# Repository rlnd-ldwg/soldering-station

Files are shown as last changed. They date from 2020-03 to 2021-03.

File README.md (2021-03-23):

# soldering-station
### based on Weller soldering tip

improved fork from ArduinoHannover/Maiskolben  

features:  
* optional referenzvoltage for A/D conversion based on LM4040
* optional PWM controlled TFT brightness
* using ATmega328p as mcu
* rotary encoder to set temperature
* prototyping area for own development
* voltage converter for I2C interface

for more information see the original README under README-MAISKOLBEN.md (german)

Beim Drehenkoder müssen A und S1 getauscht werden!

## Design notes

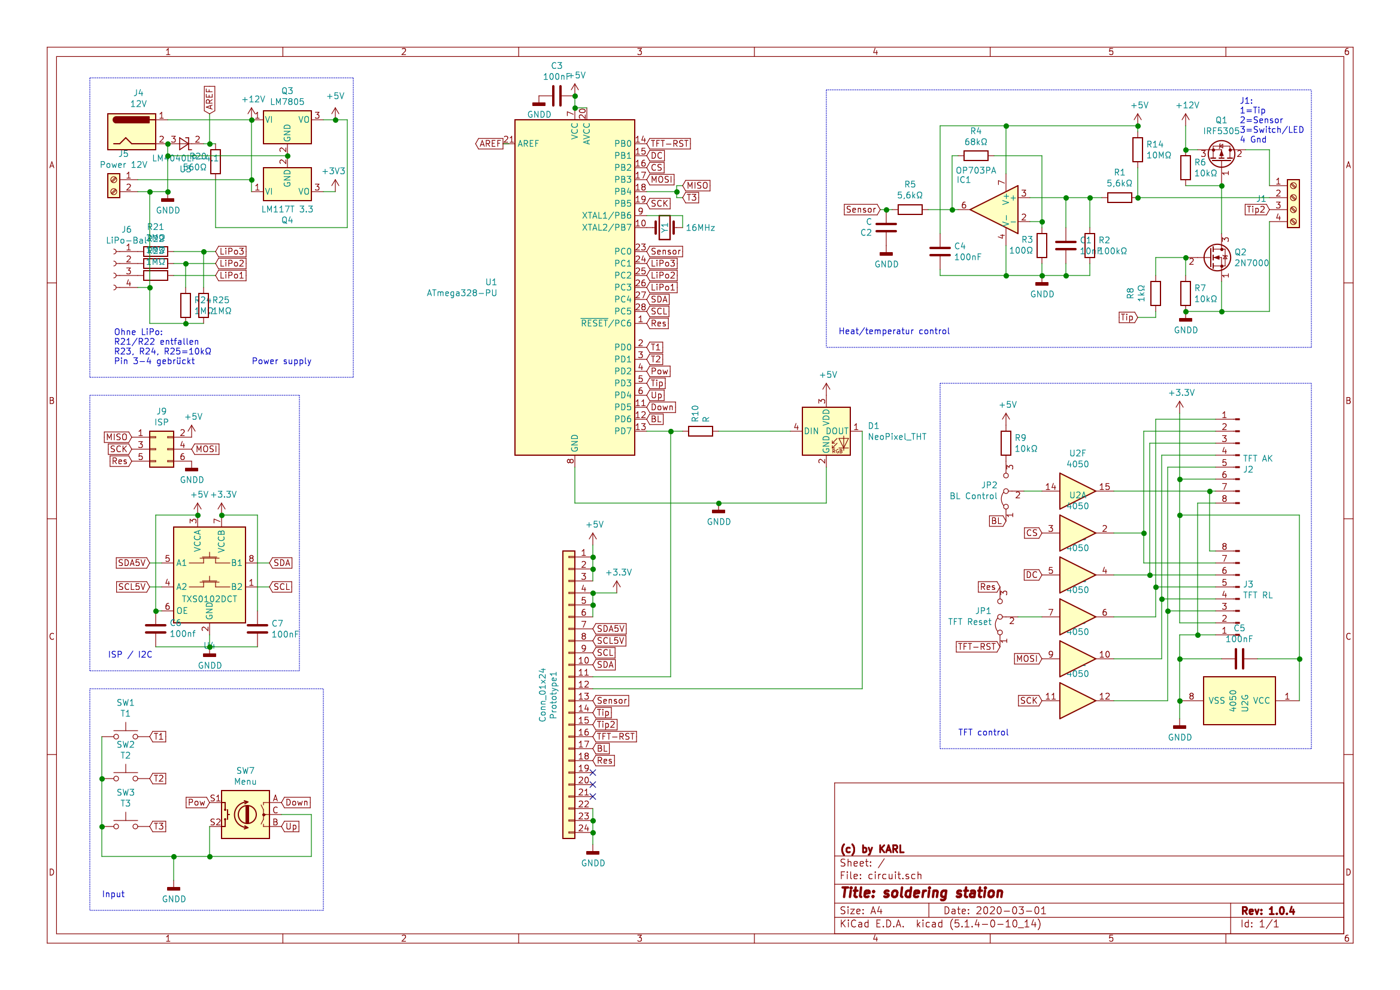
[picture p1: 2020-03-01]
images/circuit.png

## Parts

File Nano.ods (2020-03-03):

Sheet: Pinout ATmega
ATmega328 | 28 PDIP | 32 TQFP | Maiskolben | neu | Arduino | Function
PC6 | 1 | 29 | Reset | Reset |  |  | PCINT14 | RESET
PD0 | 2 | 30 | - | T1 | D0 |  | PCINST16 | RXD
PD1 | 3 | 31 | - | T2 | D1 |  | PCINT17 | TXD
PD2 | 4 | 32 | Power | Power | D2 |  | PCINT18 | INT0
PD3 | 5 | 1 | Heat PWM | Heat PWM | D3 | OC2B | PCINT19 | INT1
PD4 | 6 | 2 | Down | T+(Up) | D4 | T0 | PCINT20 | XCK
PB6 | 9 |  | Xtal | Xtal
PB7 | 10 |  | Xtal | Xtal
PD5 | 11 | 9 | LED | T-(Down) | D5 | T1 | PCINT21 | OC0B
PD6 | 12 | 10 | Up | BL | D6 | AIN0 | PCINT22 | OC0A
PD7 | 13 | 11 | T3 | LED | D7 | AIN1 | PCINT23
PB0 | 14 | 12 | T2 | TFT Reset | D8 | CLK0 | PCINT0 | ICP1
PB1 | 15 | 13 | T1 | DC | D9 | OC1A | PCINT1
PB2 | 16 | 14 | CS | CS | D10 | OC1B | PCINT2 | SS
PB3 | 17 | 15 | MOSI | MOSI | D11 | OC2A | PCINT3 | MOSI
PB4 | 18 | 16 | - | T3 | D12 |  | PCINT4 | MISO
PB5 | 19 | 17 | SCK | SCK | D13 |  | PCINT5 | SCK
AREF | 21 | 21 | - | Vref
PC0 | 23 | 23 | Temp | Tempsensor | A0 | ADC0 | PCINT8
PC1 | 24 | 24 | Stdb | Bat3 | A1 | ADC1 | PCINT9
PC2 | 25 | 25 | Bat3 | Bat2 | A2 | ADC2 | PCINT10
PC3 | 26 | 26 | Bat2 | Bat1 | A3 | ADC3 | PCINT11
PC4 | 27 | 27 | Bat1 | SDA | A4 | ADC4 | PCINT12 | SDA
PC5 | 28 | 28 | DC | SCL | A5 | ADC5 | PCINT13 | SCL
ADC6 |  | 19 |  |  | A6 | ADC6
ADC7 |  | 22 |  |  | A7 | ADC7

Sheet: BOM
Source: | /Users/roland/Projects/soldering-station/KiCad/circuit.sch
Date: | 2020 March 01, Sunday 12:34:07 | Tool: Eeschema (5.1.4-0-10_14)
Component Count: | 49
Ref | Value | Footprint | Datasheet | Manufacturer | Vendor
C1 | 10nF | Capacitor_THT:C_Disc_D4.3mm_W1.9mm_P5.00mm | ~
C2 | C | Capacitor_THT:C_Disc_D4.3mm_W1.9mm_P5.00mm | ~
C3 | 100nF | Capacitor_THT:C_Disc_D4.3mm_W1.9mm_P5.00mm | ~
C4 | 100nF | Capacitor_THT:C_Disc_D4.3mm_W1.9mm_P5.00mm | ~
C5 | 100nF | Capacitor_THT:C_Disc_D4.3mm_W1.9mm_P5.00mm | ~
C6 | 100nf | Capacitor_THT:C_Disc_D4.3mm_W1.9mm_P5.00mm | ~
C7 | 100nF | Capacitor_THT:C_Disc_D4.3mm_W1.9mm_P5.00mm | ~
D1 | NeoPixel_THT | LED_THT:LED_D5.0mm-4_RGB | https://www.adafruit.com/product/1938
IC1 | OP703PA | Package_DIP:DIP-8_W7.62mm | https://www.analog.com/media/en/technical-documentation/data-sheets/OP179_279.pdf
J1 | Soldering iron | TerminalBlock_Phoenix:TerminalBlock_Phoenix_MKDS-1,5-4-5.08_1x04_P5.08mm_Horizontal | ~
J2 | TFT AK | my:TFT-1.8-AK | ~
J3 | TFT RL | my:TFT-1.8-RGB | ~
J4 | 12V | Connector_BarrelJack:BarrelJack_CUI_PJ-063AH_Horizontal | ~
J5 | Power 12V | TerminalBlock_Phoenix:TerminalBlock_Phoenix_MKDS-1,5-2-5.08_1x02_P5.08mm_Horizontal | ~
J6 | LiPo-Bal | Connector_JST:JST_EH_S4B-EH_1x04_P2.50mm_Horizontal | ~
J9 | ISP | Connector_PinHeader_2.54mm:PinHeader_2x03_P2.54mm_Vertical | ~
JP1 | TFT Reset | Connector_PinHeader_2.54mm:PinHeader_1x03_P2.54mm_Vertical | ~
JP2 | BL Control | Connector_PinHeader_2.54mm:PinHeader_1x03_P2.54mm_Vertical | ~
Prototype1 | Conn_01x24 | my:Proto1x24 | ~
Q1 | IRF5305 | Package_TO_SOT_THT:TO-220-3_Horizontal_TabDown | http://www.infineon.com/dgdl/irf4905.pdf?fileId=5546d462533600a4015355e32165197c
Q2 | 2N7000 | Package_TO_SOT_THT:TO-92_Inline | https://www.fairchildsemi.com/datasheets/2N/2N7000.pdf
Q3 | LM7805 | Package_TO_SOT_THT:TO-220-3_Horizontal_TabDown | http://www.fairchildsemi.com/ds/LM/LM7805.pdf
Q4 | LM117T 3.3 | Package_TO_SOT_THT:TO-220-3_Horizontal_TabDown | http://www.fairchildsemi.com/ds/LM/LM7805.pdf
R1 | 5,6kΩ | Resistor_THT:R_Axial_DIN0204_L3.6mm_D1.6mm_P7.62mm_Horizontal | ~
R2 | 100kΩ | Resistor_THT:R_Axial_DIN0204_L3.6mm_D1.6mm_P7.62mm_Horizontal | ~
R3 | 100Ω | Resistor_THT:R_Axial_DIN0204_L3.6mm_D1.6mm_P7.62mm_Horizontal | ~
R4 | 68kΩ | Resistor_THT:R_Axial_DIN0204_L3.6mm_D1.6mm_P7.62mm_Horizontal | ~
R5 | 5,6kΩ | Resistor_THT:R_Axial_DIN0204_L3.6mm_D1.6mm_P7.62mm_Horizontal | ~
R6 | 10kΩ | Resistor_THT:R_Axial_DIN0204_L3.6mm_D1.6mm_P7.62mm_Horizontal | ~
R7 | 10kΩ | Resistor_THT:R_Axial_DIN0204_L3.6mm_D1.6mm_P7.62mm_Horizontal | ~
R8 | 1kΩ | Resistor_THT:R_Axial_DIN0204_L3.6mm_D1.6mm_P7.62mm_Horizontal | ~
R9 | 10kΩ | Resistor_THT:R_Axial_DIN0204_L3.6mm_D1.6mm_P7.62mm_Horizontal | ~
R10 | 220Ω/0Ω | Resistor_THT:R_Axial_DIN0204_L3.6mm_D1.6mm_P7.62mm_Horizontal | ~
R14 | 10MΩ | Resistor_THT:R_Axial_DIN0204_L3.6mm_D1.6mm_P7.62mm_Horizontal | ~
R20 | 560Ω | Resistor_THT:R_Axial_DIN0204_L3.6mm_D1.6mm_P7.62mm_Horizontal | ~
R21 | 2MΩ | Resistor_THT:R_Axial_DIN0204_L3.6mm_D1.6mm_P7.62mm_Horizontal | ~
R22 | 1MΩ | Resistor_THT:R_Axial_DIN0204_L3.6mm_D1.6mm_P7.62mm_Horizontal | ~
R23 | 1MΩ | Resistor_THT:R_Axial_DIN0204_L3.6mm_D1.6mm_P7.62mm_Horizontal | ~
R24 | 1MΩ | Resistor_THT:R_Axial_DIN0204_L3.6mm_D1.6mm_P7.62mm_Horizontal | ~
R25 | 1MΩ | Resistor_THT:R_Axial_DIN0204_L3.6mm_D1.6mm_P7.62mm_Horizontal | ~
SW1 | T1 | Button_Switch_THT:SW_Tactile_Straight_KSL0Axx1LFTR | ~
SW2 | T2 | Button_Switch_THT:SW_Tactile_Straight_KSL0Axx1LFTR | ~
SW3 | T3 | Button_Switch_THT:SW_Tactile_Straight_KSL0Axx1LFTR | ~
SW7 | Menu | Rotary_Encoder:RotaryEncoder_Alps_EC11E-Switch_Vertical_H20mm | ~
U1 | ATmega328-PU | Package_DIP:DIP-28_W7.62mm | http://ww1.microchip.com/downloads/en/DeviceDoc/ATmega328_P%20AVR%20MCU%20with%20picoPower%20Technology%20Data%20Sheet%2040001984A.pdf
U2 | 4050 | Package_DIP:DIP-16_W7.62mm | http://www.intersil.com/content/dam/intersil/documents/cd40/cd4050bms.pdf
U3 | LM4040LP-4.1 | Package_TO_SOT_THT:TO-92_Inline | http://www.ti.com/lit/ds/symlink/lm4040-n.pdf
U4 | TXS0102DCT | Package_DIP:DIP-8_W7.62mm | http://www.ti.com/lit/gpn/txs0102
Y1 | 16MHz | Crystal:Crystal_HC49-U_Vertical | ~

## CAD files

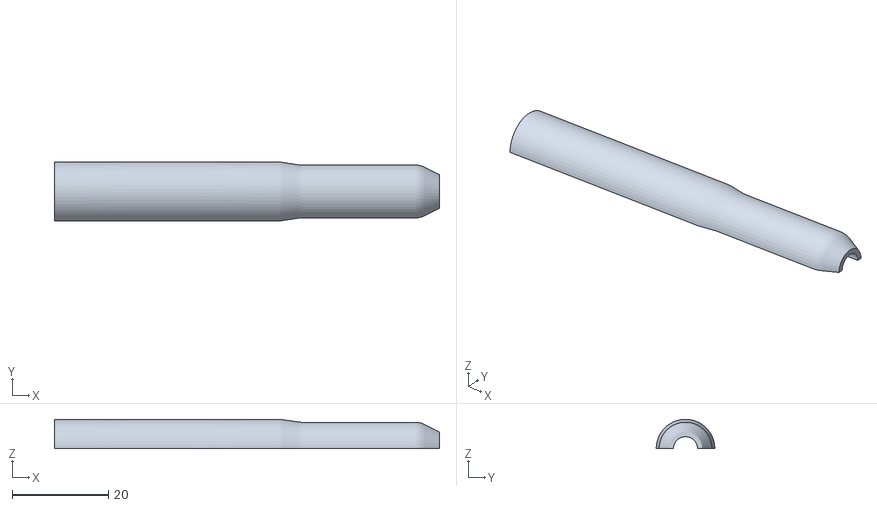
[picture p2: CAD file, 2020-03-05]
3D/Halterhälfte1.stl
80.0 x 12.2 x 6.10

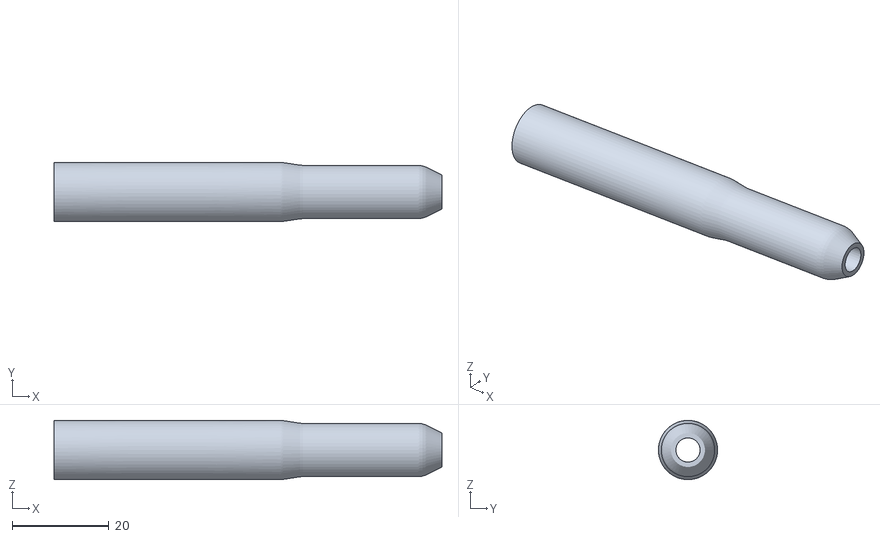
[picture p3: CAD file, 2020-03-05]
3D/Halter1.stl
80.0 x 12.2 x 12.2

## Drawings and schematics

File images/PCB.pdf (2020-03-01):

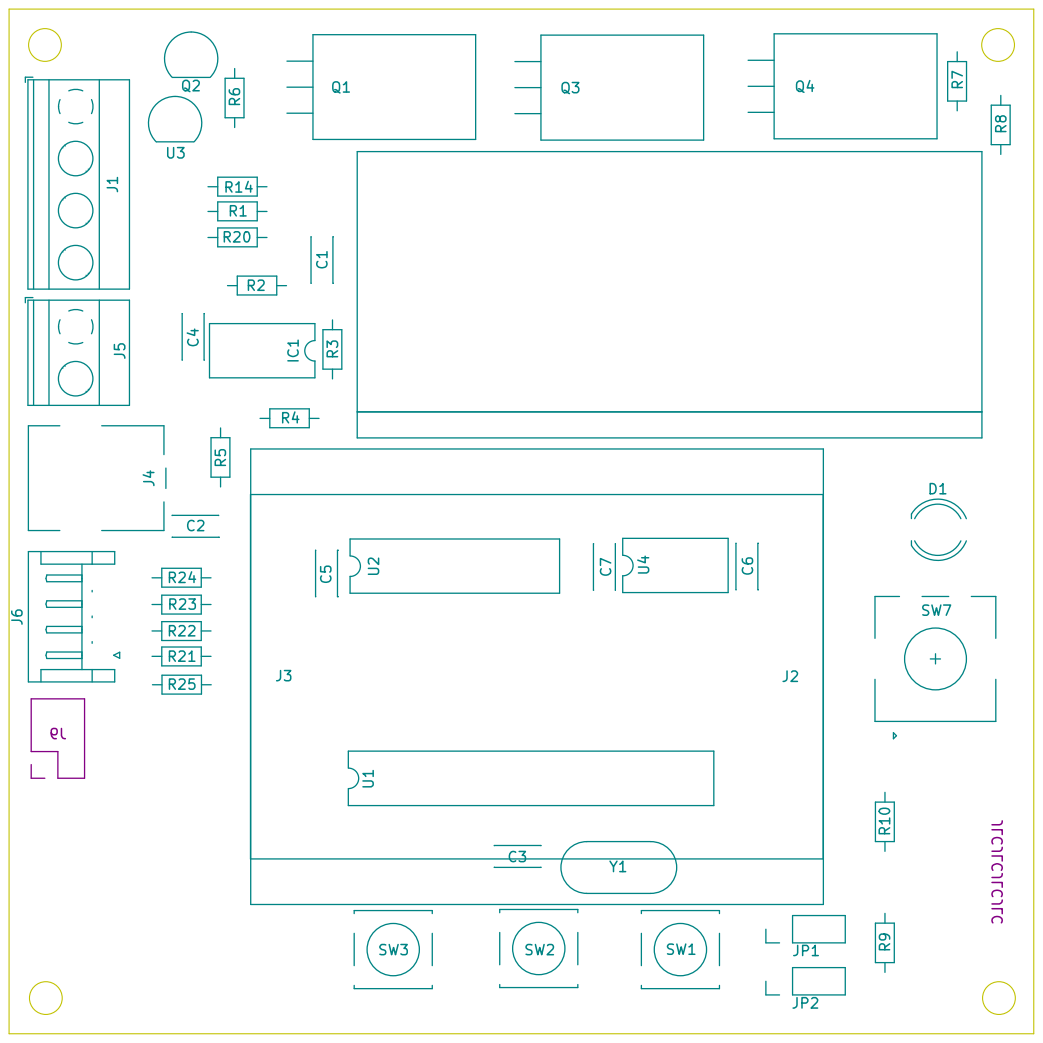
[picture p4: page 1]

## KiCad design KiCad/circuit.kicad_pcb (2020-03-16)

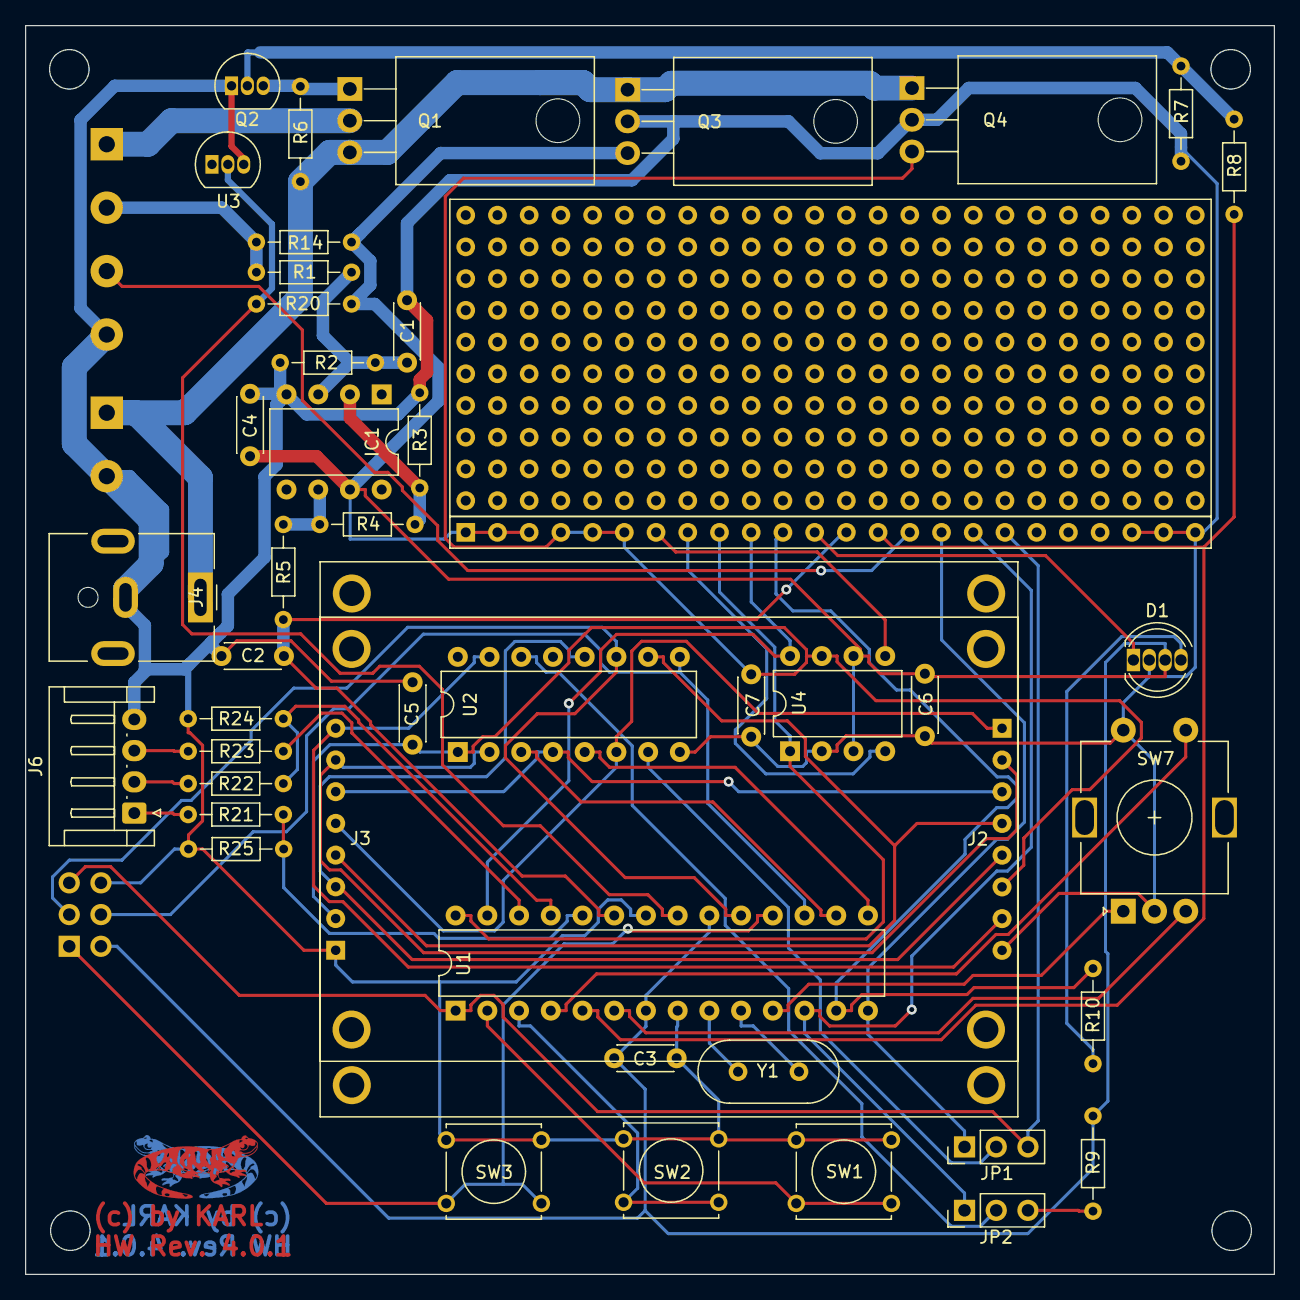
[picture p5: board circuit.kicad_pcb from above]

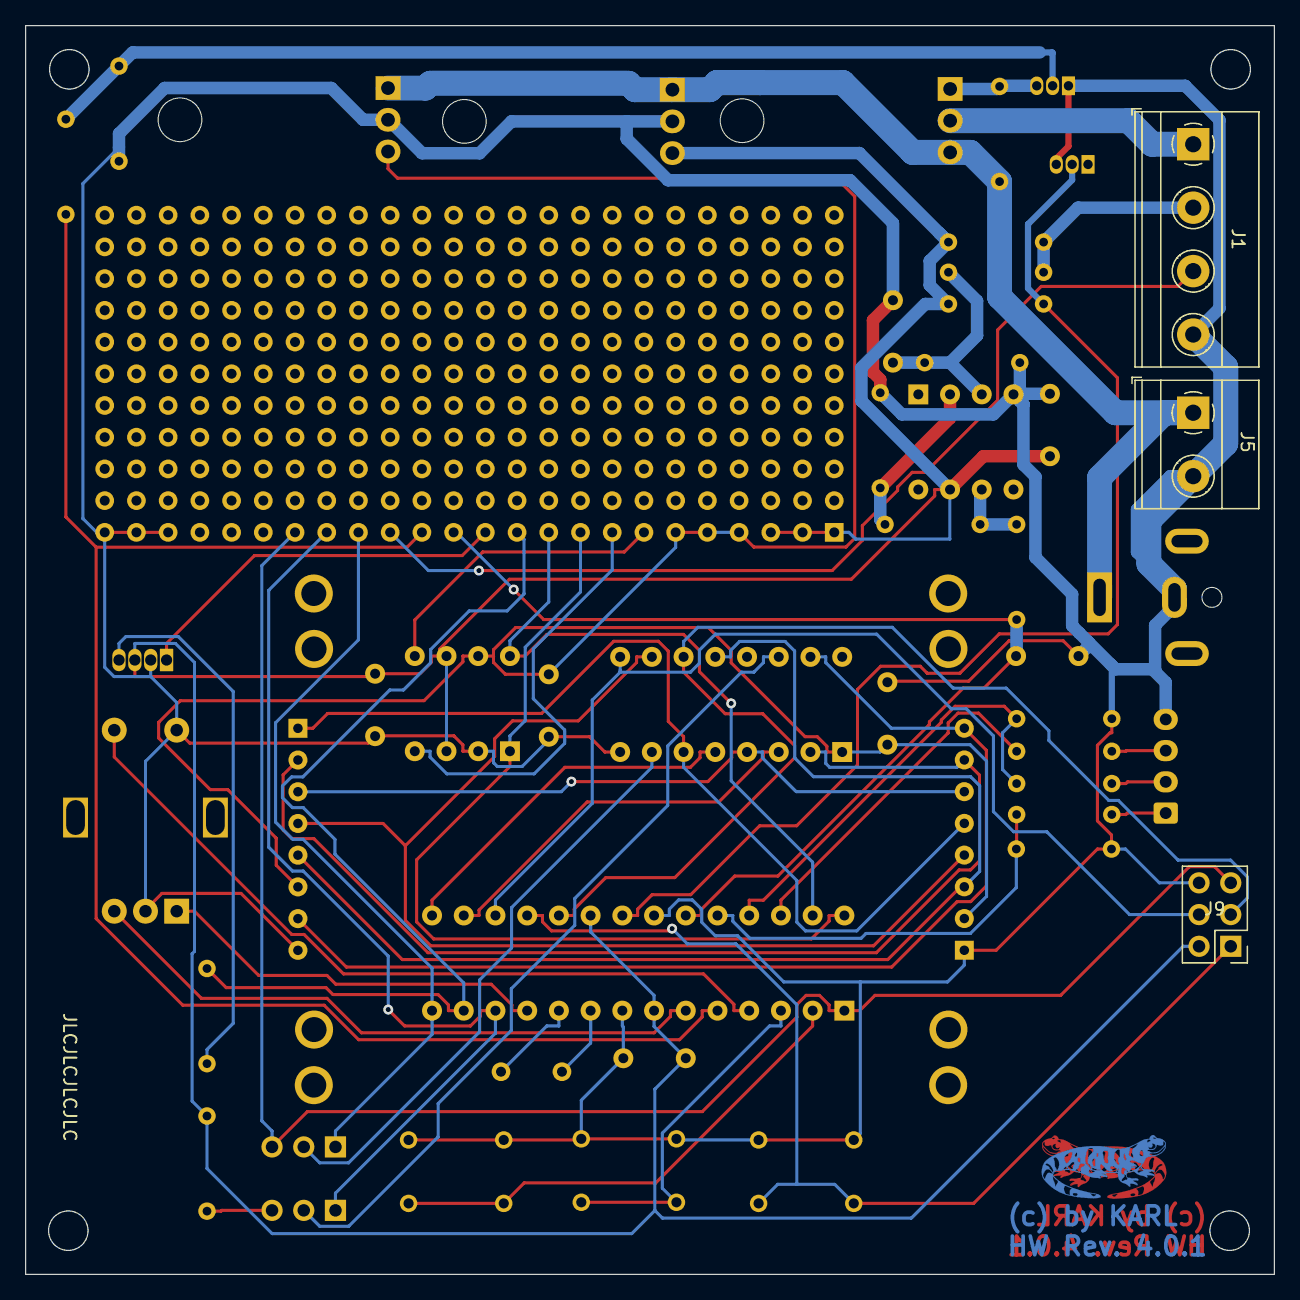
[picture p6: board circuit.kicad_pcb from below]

Board: 2 copper layers, 100.0 x 100.0 mm, 52 parts (4 on the bottom side), 52 nets.

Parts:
10x24: Proto10x24
C1: 10nF; C_Disc_D4.3mm_W1.9mm_P5.00mm
C2: C; C_Disc_D4.3mm_W1.9mm_P5.00mm
C3, C4, C5, C7: 100nF; C_Disc_D4.3mm_W1.9mm_P5.00mm
C6: 100nf; C_Disc_D4.3mm_W1.9mm_P5.00mm
D1: NeoPixel_THT; LED_D5.0mm-4_RGB
IC1: OP703PA; DIP-8_W7.62mm
J1: Soldering iron; TerminalBlock_Phoenix_MKDS-1,5-4-5.08_1x04_P5.08mm_Horizont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
J2: TFT AK; TFT-1.8-AK
J3: TFT RL; TFT-1.8-RGB
J4: 12V; BarrelJack_CUI_PJ-063AH_Horizontal
J5: Power 12V; TerminalBlock_Phoenix_MKDS-1,5-2-5.08_1x02_P5.08mm_Horizont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
J6: LiPo-Bal; JST_EH_S4B-EH_1x04_P2.50mm_Horizontal
J9: ISP; PinHeader_2x03_P2.54mm_Vertical
JP1: TFT Reset; PinHeader_1x03_P2.54mm_Vertical
JP2: BL Control; PinHeader_1x03_P2.54mm_Vertical
Logo1, Logo1#2: LOGO; Logo
Prototype1: Conn_01x24; Proto1x24
Q1: IRF5305; TO-220-3_Horizontal_TabDown
Q2: 2N7000; TO-92_Inline
Q3: LM7805; TO-220-3_Horizontal_TabDown
Q4: LM117T 3.3; TO-220-3_Horizontal_TabDown
R1, R5: 5,6kΩ; R_Axial_DIN0204_L3.6mm_D1.6mm_P7.62mm_Horizontal
R2: 100kΩ; R_Axial_DIN0204_L3.6mm_D1.6mm_P7.62mm_Horizontal
R3: 100Ω; R_Axial_DIN0204_L3.6mm_D1.6mm_P7.62mm_Horizontal
R4: 68kΩ; R_Axial_DIN0204_L3.6mm_D1.6mm_P7.62mm_Horizontal
R6, R7, R9: 10kΩ; R_Axial_DIN0204_L3.6mm_D1.6mm_P7.62mm_Horizontal
R8: 1kΩ; R_Axial_DIN0204_L3.6mm_D1.6mm_P7.62mm_Horizontal
R10: 220Ω/0Ω; R_Axial_DIN0204_L3.6mm_D1.6mm_P7.62mm_Horizontal
R14: 10MΩ; R_Axial_DIN0204_L3.6mm_D1.6mm_P7.62mm_Horizontal
R20: 560Ω; R_Axial_DIN0204_L3.6mm_D1.6mm_P7.62mm_Horizontal
R21: 2MΩ; R_Axial_DIN0204_L3.6mm_D1.6mm_P7.62mm_Horizontal
R22, R23, R24, R25: 1MΩ; R_Axial_DIN0204_L3.6mm_D1.6mm_P7.62mm_Horizontal
SW1: T1; SW_Tactile_Straight_KSL0Axx1LFTR
SW2: T2; SW_Tactile_Straight_KSL0Axx1LFTR
SW3: T3; SW_Tactile_Straight_KSL0Axx1LFTR
SW7: Menu; RotaryEncoder_Alps_EC11E-Switch_Vertical_H20mm
U1: ATmega328-PU; DIP-28_W7.62mm
U2: 4050; DIP-16_W7.62mm
U3: LM4040LP-4.1; TO-92_Inline
U4: TXS0102DCT; DIP-8_W7.62mm
Y1: 16MHz; Crystal_HC49-U_Vertical

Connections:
+3V3: C5.2, C7.1, J2.6, J3.2, Prototype1.4, Prototype1.5, Prototype1.6, Q4.3, U2.1, U4.7
+5V: C3.1, C4.1, C6.2, D1.3, IC1.7, J9.2, Prototype1.1, Prototype1.2, Prototype1.3, Q3.3, R9.1, R14.1, R20.2, U1.7, U1.20, U4.3, U4.6
+12V: J4.1, J5.1, Q1.3, Q3.1, Q4.1, R6.1
AREF: R20.1, U1.21, U3.2
BL: JP2.1, Prototype1.17, U1.12
CS: U1.16, U2.3
DC: U1.15, U2.5
Down: SW7.A, U1.11
GNDD: C1.2, C2.1, C3.2, C4.2, C5.1, C6.1, C7.2, D1.2, IC1.4, J1.4, J2.8, J3.1, J4.2, J5.2, J6.4, J9.6, Prototype1.22, Prototype1.23, Prototype1.24, Q2.1, Q3.2, Q4.2, R2.2, R3.1, R7.2, R24.2, R25.2, SW1.1, SW2.1, SW3.1, SW7.C, SW7.S2, U1.8, U1.22, U2.8, U3.3, U4.2
LiPo1: R23.1, U1.26
LiPo2: R22.1, R24.1, U1.25
LiPo3: R21.1, R25.1, U1.24
MISO: J9.1, SW3.2, U1.18
MOSI: J9.4, U1.17, U2.9
unnamed: C1.1, IC1.3, R1.1, R2.1
unnamed: D1.1, Prototype1.12
unnamed: D1.4, R10.2
unnamed: IC1.2, R3.2, R4.1
unnamed: IC1.6, R4.2, R5.2
unnamed: J1.1, Q1.2
unnamed: J1.2, R1.2, R14.2
unnamed: J2.1, J3.5, U2.6
unnamed: J2.2, J3.7, U2.2
unnamed: J2.3, J3.6, U2.4
unnamed: J2.4, J3.4, U2.10
unnamed: J2.5, J3.3, U2.12
unnamed: J2.7, J3.8, U2.15
unnamed: J6.1, R21.2
unnamed: J6.2, R22.2
unnamed: J6.3, R23.2
unnamed: JP1.2, U2.7
unnamed: JP2.2, U2.14
unnamed: JP2.3, R9.2
unnamed: Prototype1.11, R10.1, U1.13
unnamed: Q1.1, Q2.3, R6.2
unnamed: Q2.2, R7.1, R8.2
unnamed: U1.9, Y1.2
unnamed: U1.10, Y1.1
Pow: SW7.S1, U1.4
Res: J9.5, JP1.3, Prototype1.18, U1.1
SCK: J9.3, U1.19, U2.11
SCL: Prototype1.9, U1.28, U4.1
SCL5V: Prototype1.8, U4.4
SDA: Prototype1.10, U1.27, U4.8
SDA5V: Prototype1.7, U4.5
Sensor: C2.2, Prototype1.13, R5.1, U1.23
T1: SW1.2, U1.2
T2: SW2.2, U1.3
TFT-RST: JP1.1, Prototype1.16, U1.14
Tip: Prototype1.14, R8.1, U1.5
Tip2: J1.3, Prototype1.15
Up: SW7.B, U1.6

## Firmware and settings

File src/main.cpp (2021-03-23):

#include <Arduino.h>
#include "definitions.h"

uint8_t oled_buffer[OLED_SCREEN_WIDTH + 1];
uint8_t oled_buffer_index = 0;

volatile uint16_t adc_values[4];
volatile uint8_t adc_count = 0;
volatile uint8_t pwm = 0;
volatile double adc;
volatile double target_adc = ADC_STBY;
volatile double target_adc_prev = ADC_STBY;
volatile double pid_val;
volatile state_t state = STATE_STANDBY;
volatile state_t last_state = STATE_OFF;
volatile uint8_t adc_set_changed = 0;
uint16_t adc_set[3] = {ADC_SET1, ADC_SET2, ADC_SET3};
uint8_t buttons[3] = {SW_T1, SW_T2, SW_T3};
uint8_t click_count[3] = {0, 0, 0};
uint8_t stb_count = 0;
uint8_t selected_set = 0;
uint8_t clear_screen = 0;
double kp = 0.4;
double ki = 0.008;
double kd = 0.0;

#ifdef USE_SSD1306
Adafruit_SSD1306 oled(OLED_SCREEN_WIDTH, OLED_SCREEN_HEIGHT, &Wire, OLED_RESET);
#endif

#ifdef USE_TFT_RESET
TFT_ILI9163C tft = TFT_ILI9163C(TFT_CS,  TFT_DC, STBY_NO);
#else
TFT_ILI9163C tft = TFT_ILI9163C(TFT_CS,  TFT_DC);
#endif

PID pid((double*)&adc, (double*)&pid_val, (double*)&target_adc, kp, ki, kd, DIRECT);

uint16_t getTemperature(double adc) {
    return round(adc < 230 ? (adc * 0.3886 + 61) : (adc * 0.3374 + 73));
}

uint16_t EEPROMreadInt(uint8_t index) {
    uint8_t h_byte, l_byte;

    l_byte = EEPROM.read(index);
    h_byte = EEPROM.read(index + 1);
    return l_byte + ((h_byte << 8) & 0xFF00);
}

void EEPROMwriteInt(uint16_t value, uint8_t index) {
    uint8_t h_byte, l_byte;

    l_byte = value & 0xFF;
    h_byte = (value >> 8) & 0xFF;
    EEPROM.write(index, l_byte);
    EEPROM.write(index + 1, h_byte);
}

uint16_t readADC(void) {
    uint16_t temp[8], tmp;
    uint8_t size = 8;

	analogRead(ADC_PIN);

    for (int i = 0; i < size; i++) {
        temp[i] = analogRead(ADC_PIN);
        delayMicroseconds(2);
    }

    // sort
    for(int i = 0; i < (size - 1); i++) {
        for(int j = 0; j < (size - (i + 1)); j++) {
                if(temp[j] > temp[j + 1]) {
                    tmp = temp[j];
                    temp[j] = temp[j + 1];
                    temp[j + 1] = tmp;
                }
        }
    }

    // median
    return (temp[size / 2 - 1] + temp[size / 2]) / 2;
}

// timer interrupt
ISR(TIMER2_OVF_vect) {
    noInterrupts();

    delayMicroseconds(1600);
    digitalWrite(HEARTBEAT_PIN, HIGH);

    adc_values[adc_count] = readADC();
    adc_count++;
    if (adc_count == 4) {
        adc_count = 0;
        uint16_t tmp = 0;
        for (uint8_t i = 0; i < 4; i++) {tmp += adc_values[i];}
        adc = double(tmp / 4.0);
        /*if (target_adc > 0) {
            double err = abs(target_adc - adc);
            if (err < 20) {
                kp = 0.2;
                ki = 0.1;
                kd = 0.0;
                pid.SetTunings(kp, ki, kd);
            } else {
                if (err < 60) {
                    kp = 0.01;
                    ki = 0.0;
                    kd = 0.0;
                    pid.SetTunings(kp, ki, kd);
                } else {
                    kp = 0.2;
                    ki = 0.0;
                    kd = 0.0;
                    pid.SetTunings(kp, ki, kd);
                }
            }
        }*/

        pid.Compute();
        pwm = pid_val;
        analogWrite(HEATER_PWM_PIN, pwm);
    }

    // read buttons
    if (digitalRead(SW_STBY) == LOW) stb_count++; else stb_count = 0;

    for (uint8_t i = 0; i < 3; i++) {
        if (digitalRead(buttons[i]) == LOW) {
            if (click_count[i] >= LONG_PRESS) {
                if (state == STATE_ON) {
                    if (adc_set[i] != target_adc) adc_set_changed = 1;
                    adc_set[i] = target_adc;
                    selected_set = i + 1;
                }
            } else click_count[i]++;
        } else {
            if (click_count[i] >= SHORT_PRESS) {
                selected_set = i + 1;
                target_adc = adc_set[i];
                state = STATE_ON;
            }
            click_count[i] = 0;
        }
    }

    if (stb_count == SHORT_PRESS) {
        selected_set = 0;
        switch (state) {
            case STATE_OFF:
                state = STATE_STANDBY;
                target_adc = ADC_STBY;
                last_state = STATE_OFF;
                break;

            case STATE_ON:
                state = STATE_STANDBY;
                target_adc = ADC_STBY;
                last_state = STATE_ON;
                break;

            case STATE_STANDBY:
                if (last_state == STATE_OFF) {
                    state = STATE_ON;
                    target_adc = adc_set[0];
                } else {
                    state = STATE_OFF;
                    target_adc = 0;
                }
                last_state = STATE_STANDBY;
                break;

            default:
                break;
        }
        stb_count = 0;
    }

    digitalWrite(HEARTBEAT_PIN, LOW);
    interrupts();
}

void isr_rotaryy_encoder(void) {
    static unsigned long lastInterruptTime = 0;
    unsigned long interruptTime = millis();

    noInterrupts();
    if (state == STATE_ON) {
        if (abs(interruptTime - lastInterruptTime) > 8) {
            selected_set = 0;
            if (digitalRead(RE_CLK) != digitalRead(RE_DT)) {
                if (target_adc < ADC_MAX) target_adc += TEMP_STEP;
            } else {
                if (target_adc > ADC_MIN) target_adc -= TEMP_STEP;
            }
        }
    }
    lastInterruptTime = interruptTime;
    interrupts();
}

void serial_output(void) {
#ifdef USE_SERIAL
    char *pstr, buffer[64], kp_c[8], ki_c[8], kd_c[8], adc_c[8], target_adc_c[8], pid_val_c[8];
    dtostrf(kp, 4, 3, kp_c);
    dtostrf(ki, 4, 3, ki_c);
    dtostrf(kd, 4, 3, kd_c);
    dtostrf(adc, 4, 3, adc_c);
    dtostrf(target_adc, 4, 3, target_adc_c);
    dtostrf(pid_val, 4, 3, pid_val_c);
    sprintf(buffer, "%s;%s;%s;%d;%d;%s\n", kp_c, ki_c, kd_c, int(adc), int(target_adc), pid_val_c);
    pstr = buffer;
    while (*pstr != 0) {
        // wait till the data has been transmitted
        while (!( UCSR0A & (1<<UDRE0)));
        UDR0 = *pstr++;
    }
#endif
}

void display_oled(void) {
#ifdef USE_SSD1306
    	oled.clearDisplay();
    	oled.setTextSize(1);
		oled.setTextColor(WHITE);
		oled.setCursor(0,0);
		oled.print("PWM: ");
		oled.println(pwm);
		oled.setCursor(0,10);
		oled.print("ADC: ");
		oled.println(adc);
		oled.setCursor(0,20);
		oled.print("TGT: ");
		oled.println(target_adc);
		// graph
		/*for (int i = 0; i < OLED_SCREEN_WIDTH - OLED_SCREEN_OFFSET; i++) {
			uint8_t pixelColor = SSD1306_WHITE;
			if (oled_buffer[i] > 0) {
				oled.drawPixel(i + OLED_SCREEN_OFFSET, OLED_SCREEN_HEIGHT - 1 - oled_buffer[i], SSD1306_WHITE);
			}
		}
		// ca. 60 sec
		if (oled_buffer_index == OLED_SCREEN_DIVIDER) {
			// shift buffer for one pixel right
			for (int i = OLED_SCREEN_WIDTH; i > 0; i--) {
				oled_buffer[i] = oled_buffer[i - 1];
			}
			int value = (cur_t - TEMP_MIN) / 8;
			if (value < 0) value = 0;
			if (value >= OLED_SCREEN_HEIGHT) value = OLED_SCREEN_HEIGHT - 1;
			oled_buffer[0] = value;
			oled_buffer_index = 0;
		} else oled_buffer_index++;*/
		oled.display();
#endif
}

void display_tft(void) {
    uint16_t text_color;
    uint8_t height = 64;
    uint8_t width = 10;
    uint8_t origin_x = 149;
    uint8_t	origin_y = 24;

    if (state == STATE_ERROR) {
        if (clear_screen == 1) {tft.fillScreen(TFT_BLACK); clear_screen = 0;}
        tft.setTextSize(3);
        tft.setTextColor(TFT_RED, TFT_BLACK);
        tft.setCursor(10,26);
        tft.print(F("ERROR"));
        tft.setTextSize(2);
        tft.setCursor(10,60);
        if (adc == 1023) tft.print(F("No tip"));
        else tft.print(F("Not heating"));
        return;
    }

    uint16_t temperature = getTemperature(adc);

    if (state == STATE_STANDBY) {text_color = TFT_YELLOW;}
    else {
        if (state == STATE_OFF) {text_color = TFT_RED;}
        else if (state == STATE_ON) {text_color = TFT_GREEN;}
    }
    tft.drawCircle(20, 63, 8, text_color);
    tft.drawCircle(20, 63, 7, text_color);
    tft.fillRect(19, 55, 3, 3, TFT_BLACK);
    tft.drawFastVLine(20, 53, 10, text_color);

    tft.setTextSize(2);
    tft.setCursor(15,112);
    if (selected_set == 1) tft.setTextColor(TFT_GREEN, TFT_BLACK); else tft.setTextColor(TFT_WHITE, TFT_BLACK);
    tft.print(round(getTemperature(adc_set[0])));
    tft.write(' ');
    if (selected_set == 2) tft.setTextColor(TFT_GREEN, TFT_BLACK); else tft.setTextColor(TFT_WHITE, TFT_BLACK);
    tft.print(round(getTemperature(adc_set[1])));
    tft.write(' ');
    if (selected_set == 3) tft.setTextColor(TFT_GREEN, TFT_BLACK); else tft.setTextColor(TFT_WHITE, TFT_BLACK);
    tft.print(round(getTemperature(adc_set[2])));

    tft.setCursor(40,26);
    tft.setTextSize(3);
    if (state == STATE_STANDBY) {
        tft.setTextColor(text_color, TFT_BLACK);
        tft.print(F("STBY "));
        tft.fillRect(origin_x - 1, origin_y - 1, width + 2, height + 2, TFT_BLACK);
    } else if (state == STATE_OFF) {
        tft.setTextColor(text_color, TFT_BLACK);
        tft.print(F("OFF  "));
        tft.fillRect(origin_x - 1, origin_y - 1, width + 2, height + 2, TFT_BLACK);
    } else {
        tft.setTextColor(TFT_GREEN, TFT_BLACK);
        tft.print(getTemperature(target_adc));
        tft.write(247);
        tft.write('C');

        uint8_t y = (target_adc - ADC_MIN) * height / (ADC_MAX - ADC_MIN);
        uint8_t x = y * width / height;
        if (target_adc != target_adc_prev) {
            target_adc_prev = target_adc;
            tft.fillRect(origin_x - 1, origin_y - 1, width + 2, height + 2, TFT_BLACK);
        }
        tft.fillTriangle(origin_x + width - x, origin_y + height - y, origin_x + width, origin_y + height - y, origin_x + width, origin_y + height, TFT_GREEN);
    }

    tft.setCursor(40,56);
    if (adc == 0) {
        tft.setTextColor(TFT_CYAN, TFT_BLACK);
        tft.print(F("COLD  "));
    } else {
        tft.setTextColor(TFT_WHITE, TFT_BLACK);
        if (temperature < 100) tft.write(' ');
        if (temperature < 10) tft.write(' ');
        tft.print(temperature);
        tft.write(247);
        tft.write('C');
    }

    uint8_t x = pwm * 160 / PID_MAX;
    uint8_t xb = 0;
    if (x > 0) xb = x + 1;
    for (int y = 0; y < 4; y++) {
        tft.drawFastHLine(0, y, x, TFT_GREEN);
        tft.drawFastHLine(xb, y, 160 - xb, TFT_BLACK);
    }
}

void setup(void) {
    // Phase Corrected PWM Mode 1
    // TCCR2A: 33 = 00100001
    // COM2A1: 0
    // COM2A0: 0
    // COM2B1: 1
    // COM2B0: 0
    // -
    // -
    // WGM21 : 0
    // WGM20 : 1

    // TCCR2B: 5 = 00000101
    // FOC2A : 0
    // FOC2B : 0
    // -
    // -
    // WGM22 : 0
    // CS22  : 1
    // CS21  : 0
    // CS20  : 1

    // TIMSK2: 0
    // OCR2A : 0
    // OCR2B : 64 = 01000000

    pinMode(HEARTBEAT_PIN, OUTPUT);
    pinMode(HEATER_PWM_PIN, OUTPUT);
    digitalWrite(HEATER_PWM_PIN, LOW);
    pinMode(ADC_PIN, INPUT);
    pinMode(SW_T1,INPUT_PULLUP);
    pinMode(SW_T2,INPUT_PULLUP);
    pinMode(SW_T3,INPUT_PULLUP);
    pinMode(SW_STBY,INPUT_PULLUP);
    pinMode(RE_CLK,INPUT_PULLUP);
    pinMode(RE_DT,INPUT_PULLUP);
    pinMode(STBY_NO, INPUT_PULLUP);
    pinMode(TFT_CS, OUTPUT);
    digitalWrite(TFT_CS, HIGH);

    pid.SetMode(AUTOMATIC);
    pid.SetOutputLimits(0, PID_MAX);
    pid.SetSampleTime(8);

    attachInterrupt(digitalPinToInterrupt(RE_CLK), isr_rotaryy_encoder, FALLING);

#ifdef USE_EXTERNAL_AREF
    analogReference(EXTERNAL);
#endif

    // Frequenz fuer PWM
    // For Arduino using ATmega8, 168 or 328* (m8, m168, m328, m238p)
    // Phase-corrected PWM by default
    // B00000xxx - 3 last bits (least significant bit or LSB) decide the divisor of the timer
    // Frequency = 16Mhz / (256 * divisor)
    // Example: divisor = 1, frequency = 16Mhz / (256) = 62.5Khz,
    //----- PWM frequency for D3 & D11 -----
    //PWM Prescaler = 1024 31Hz
    //TCCR2B = (TCCR2B & 0b11111000) | 7;
    //PWM Prescaler = 256 122Hz
    //TCCR2B = (TCCR2B & 0b11111000) | 6;
    //PWM Prescaler = 128 245Hz
    TCCR2B = (TCCR2B & 0b11111000) | 5;
    //PWM Prescaler = 64  490Hz
    //TCCR2B = (TCCR2B & 0b11111000) | 4;
    //PWM Prescaler = 32  980Hz
    //TCCR2B = (TCCR2B & 0b11111000) | 3;
    //PWM Prescaler = 8  3.9kHz
    //TCCR2B = (TCCR2B & 0b11111000) | 2;
    //PWM Prescaler = 1    31kHz - no Noise
    //TCCR2B = (TCCR2B & 0b11111000) | 1;
    TIMSK2 = (1<<TOIE2); // interrupt when TCNT2 is overflowed

    // serial port
#ifdef USE_SERIAL
    // baud rate
    // UBRRn = Fosc / 16 * baudrate - 1
    // 16000000 / 16 * 115200 - 1
    // 16000000 / 1843200 - 1 = 7.68
    // write to lower byte
    UBRR0L = (uint8_t)(8 & 0xFF);
    // write to higher byte
    UBRR0H = (uint8_t)(8 >> 8);
    // enable the transmitter and receiver
    UCSR0B |= (1 << RXEN0) | (1 << TXEN0);
#endif

    // console
#ifdef USE_SSD1306
    oled.begin(SSD1306_SWITCHCAPVCC, OLED_ADDR);
    oled.display();
    oled.clearDisplay();
    for (int i = 0; i < OLED_SCREEN_WIDTH; i++) {oled_buffer[i] = -1;}
#endif

    // tft
    tft.begin();
    tft.colorSpace(RGB_DISP);
    tft.setRotation(3);
    tft.fillScreen(TFT_BLACK);

    uint16_t check;
    uint8_t addr = 0x00;
    EEPROM.get(addr, check);
    if (check == EEPROM_CHECK) {
        addr += sizeof(check);
        EEPROM.get(addr, adc_set);
    } else {
        // first run, save default values
        EEPROM.put(addr, EEPROM_CHECK);
        addr += sizeof(check);
        EEPROM.put(addr, adc_set);
    }
}

/* *************** MAIN *************** */
int main(void) {
    uint32_t sendNext;

    init();
    setup();

    sendNext = millis();
    while (true) {
        display_oled();
        display_tft();
        if (sendNext <= millis()) {sendNext += 100; serial_output();}

        if (adc_set_changed == 1) {
            uint16_t check = EEPROM_CHECK;
            uint8_t addr = 0x00;
            addr += sizeof(check);
            EEPROM.put(addr, adc_set);
            adc_set_changed = 0;
        }

        if ((state == STATE_ON || state == STATE_STANDBY) && (adc == 1023 || adc < 100)) {
            target_adc = 0;
            state = STATE_ERROR;
            clear_screen = 1;
        }

        delay(50);
    }
}

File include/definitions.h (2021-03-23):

#include <SPI.h>
#include <Wire.h>
#include <TFT_ILI9163C.h>
#include <Adafruit_GFX.h>
#include <Adafruit_SSD1306.h>
#include <PID_v1.h>
#include <EEPROM.h>

#define USE_SSD1306
#define USE_EXTERNAL_AREF
#define USE_SERIAL
#define USE_TFT_RESET

#define PID_MAX             48
#define TEMP_STEP           1
#define ADC_STBY            228     // 150 Grad
#define ADC_SET1            672     // 300 Grad
#define ADC_SET2            820     // 350 Grad
#define ADC_SET3            970     // 400 Grad
#define ADC_MAX             ADC_SET3
#define ADC_MIN             ADC_STBY
#define SHORT_PRESS         32
#define LONG_PRESS          64

// pins
#define SW_T3               0
#define SW_T2               1
#define RE_CLK 		        2
#define HEATER_PWM_PIN      3
#define RE_DT 		        4
#define SW_STBY             5
#define STBY_NO		        8
#define TFT_DC              9
#define TFT_CS              10
#define SW_T1               12
#define ADC_PIN             A0
#define HEARTBEAT_PIN       A3

// oled display
#define OLED_SCREEN_WIDTH	128
#define OLED_SCREEN_HEIGHT	32
#define OLED_SCREEN_OFFSET 	32
#define OLED_SCREEN_DIVIDER	1
#define OLED_RESET 			4
#define OLED_ADDR 			0x3C

// tft display
#define RGB_DISP            0x0
#define BGR_DISP            0x2
#define	TFT_BLACK           0x0000
#define	TFT_BLUE            0x001F
#define	TFT_RED             0xF800
#define	TFT_GREEN           0x07E0
#define TFT_CYAN            0x07FF
#define TFT_MAGENTA         0xF81F
#define TFT_YELLOW          0xFFE0
#define TFT_WHITE           0xFFFF
#define TFT_GRAY            0x94B2

#define EEPROM_CHECK        0x4152  // AR

typedef enum state {
	STATE_OFF,
	STATE_STANDBY,
	STATE_ON,
	STATE_ERROR
} state_t;

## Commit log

2020-02-22 v0.0.6 (USE_TFT_REST)
    [Nano.ods]
2020-02-24 comment out battery code (USE_LIPO)
2020-02-26 v0.0.9 pcb v1.0.2 changed USE_TFT_RESET in main.cpp
    [circuit.kicad_pcb, circuit.sch]
2020-03-01 v1.0.1 / HW Rev. 4.0.1
    [circuit-B_Cu.gbr, circuit-B_Mask.gbr, circuit-B_SilkS.gbr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]
2020-03-05 Lötspitzenhalter als STL
    [Halter1.stl]
2020-03-16 v1.0.5 minor changes in schematic and pcb
    [circuit.kicad_pcb, circuit.sch]
2020-03-29 switch button 1 & 3 / direction rotary encoder
